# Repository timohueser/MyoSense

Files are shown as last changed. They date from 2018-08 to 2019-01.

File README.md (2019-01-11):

# MyoSense
## Overview
MyoSense is a armband designed to wirelessly track and interpret muscle activity in the forearm to predict handmovements. It uses a custom designed 2.4GHz interface to transmit the signals collected by up to eight sensors to a receiver that can be read out over a standard serial interface. The armband uses dry stainless steel electrodes incorporated into the sensor modules that can pick up the electromygraphic signal generated by muscle activity. Using external adhesive electrodes that can be attached to each sensor MyoSense is also able to read out activity of bigger muscles extendig it's possible usecases to tracking movements of all extremities. 

## Technical Details
### Sensor Modules
<p align="center">
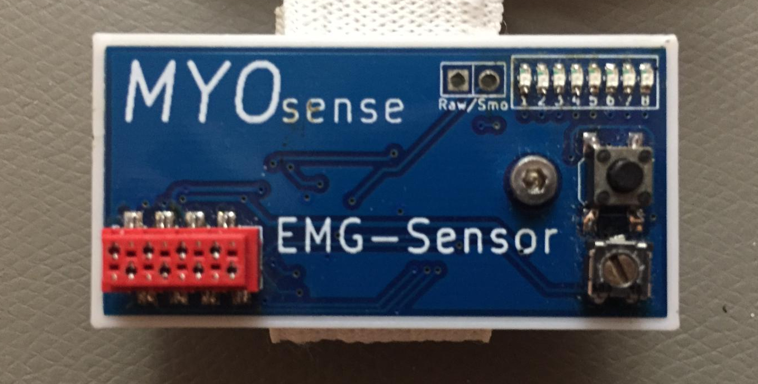
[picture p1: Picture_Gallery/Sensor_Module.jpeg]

</p>

As mentioned before the MyoSense Sensor Modules use dry stainless steel electrodes to pick up the small voltages generated by muscle activity on the skin above the monitored muscle. These voltages get amplified, bandpass-filtered and rectified using analog circuitry. It should be noted that filtering includes a 50Hz mains frequence notch filter, since the body picks this noise up very strongly. After the rectification the signal gets smoothed, or averaged, by a lowpass filter stage. This results in a DC voltage level that is proportional to the strength of muscle activity. Smoothing the signal has the advantage to be able to sample it at very low frequencies, On the other hand Information that could be extracted from the frequency of the EMG śignal, like the level of muscle fatigue is lost. 

<p align="center">
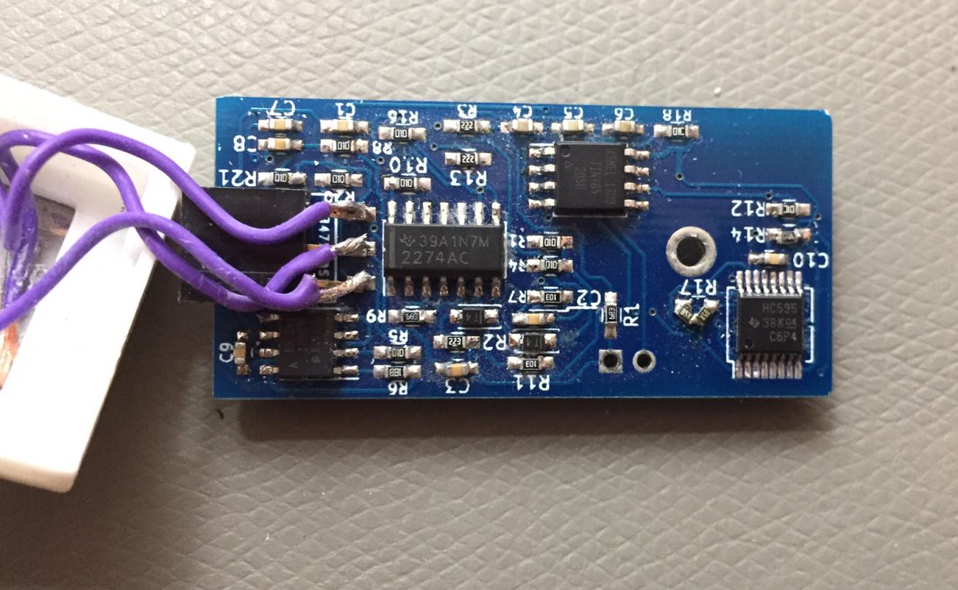
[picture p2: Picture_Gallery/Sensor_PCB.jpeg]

</p>

The processed signal gets digitized by an Attiny85 microcontroller that in turn uses an I2C interface to send the measured voltages to the control module. A push-button on the sensor allows the user to set the I2C adress of the module, allowing up to eight sensors to be used with one control module. The modules consist of a custom design PCB, 3 stainless steel plates serving as the electrodes and a 3D-printed housing. The Kicad design files for the PCB and STL files of the housing can be found in the repository. 

### Control Module
The control module not only is responsible for reading out the senors and transmitting the collected data via a 2.4GHz interfaceto the receiver unit described below, it also contains circuitry to charge a 250 mAh Lipo Battery and supply the requiered 3V and -3V power rails to the sensor modules. In addition it also contains a MCP2221 I2C/UART to USB interface IC enabling direct wired acces to the I2C bus through the same Micro-USB port that is used for charging. 
The wireless communication module used is custom designed and uses the Nordic Semi nRF24L01 2.4GHz transciever IC controlled by an Attiny85 mircrocontroller that also controlls the sensors over the I2C bus. Both the control and the sensor modules can be reprogrammed using the ICSP compatible connector that is also used to connect them with eachother. 

### Wireless receiver and GUI
<p align="center">
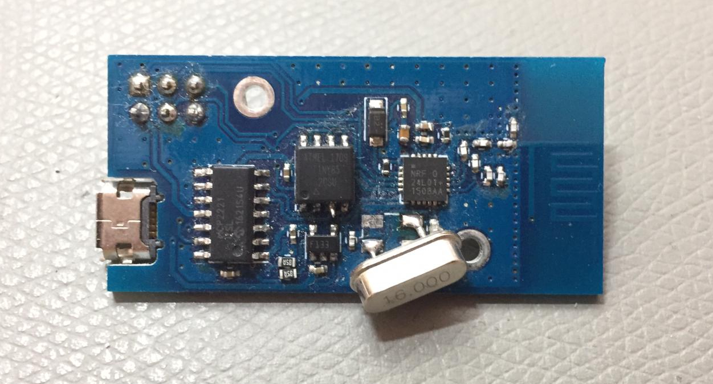
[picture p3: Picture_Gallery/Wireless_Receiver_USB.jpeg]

</p>

The wireless receiver also uses the nRF24L01 transciever and Attiny85 microcontroller as the transmitter module. The microcontroller then connects to another MCP2221 USB interface IC to be able to transmit the received data to a computer over a standard serial interface. The repository also contains an UI-Program implementet in c++ using QT that allows easy access to the receiver module and visualizes the data collected. The repository also contains a python script that implements a neural network that can be used to classify different movement patterns. At the moment this functionality is not available in the GUI, but it is planned to integrate this feature.

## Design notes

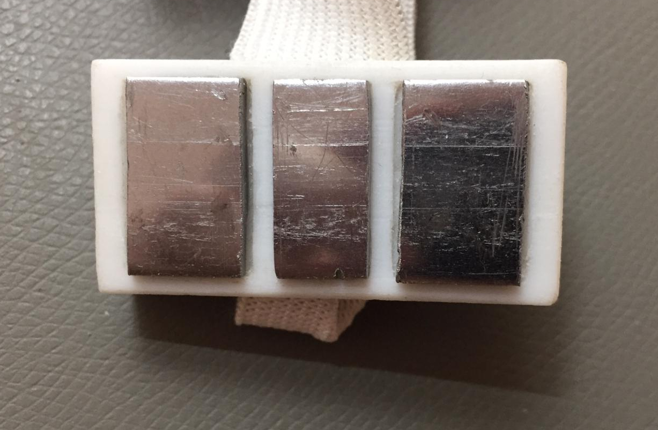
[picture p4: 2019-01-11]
Picture_Gallery/Electrode_Pads.jpeg

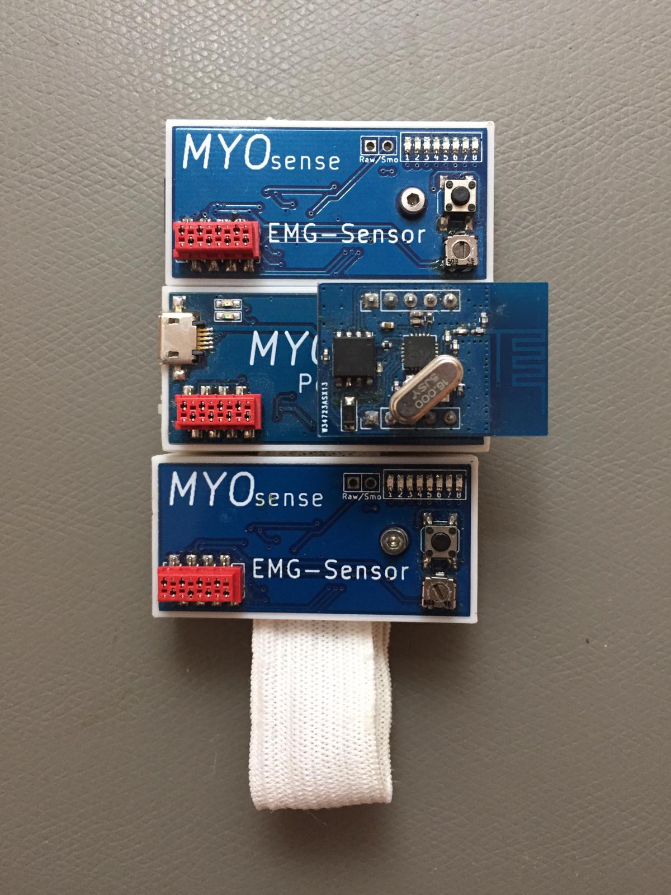
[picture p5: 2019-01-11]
Picture_Gallery/MyoSense_Armband.jpeg

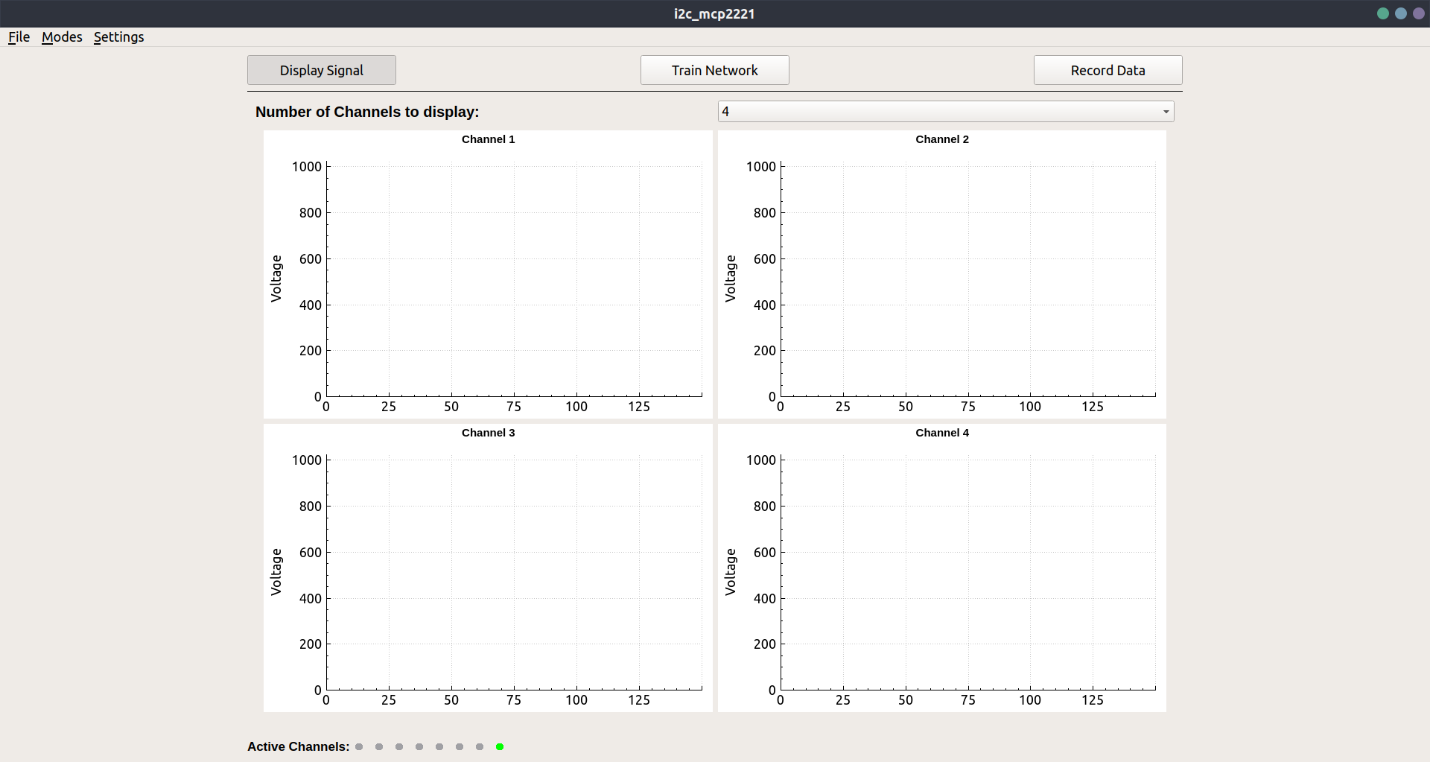
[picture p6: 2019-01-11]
Picture_Gallery/User_Interface.png

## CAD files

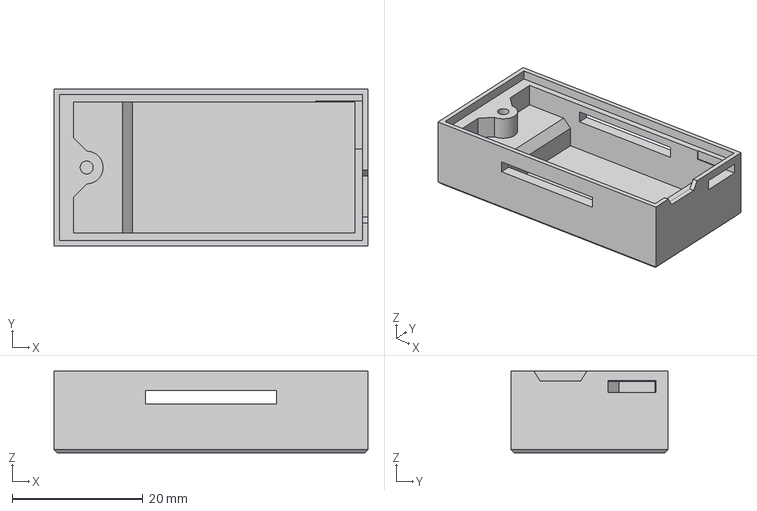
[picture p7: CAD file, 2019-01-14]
3D_Files/Control_Housing/Control_Housing.step
48.0 x 24.0 x 12.5 mm

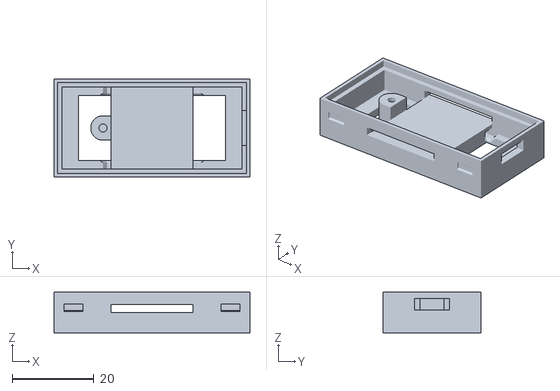
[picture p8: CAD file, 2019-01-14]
3D_Files/Sensor_Housing/Senor_Housing.stl
48.0 x 24.0 x 10.0

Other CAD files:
3D_Files/Sensor_Housing/Sensor_Housing.step
3D_Files/Control_Housing/Control_Housing.stl

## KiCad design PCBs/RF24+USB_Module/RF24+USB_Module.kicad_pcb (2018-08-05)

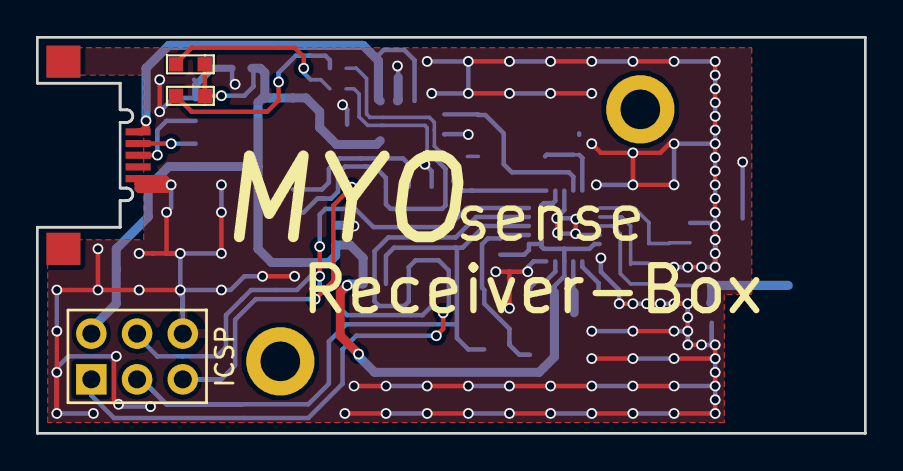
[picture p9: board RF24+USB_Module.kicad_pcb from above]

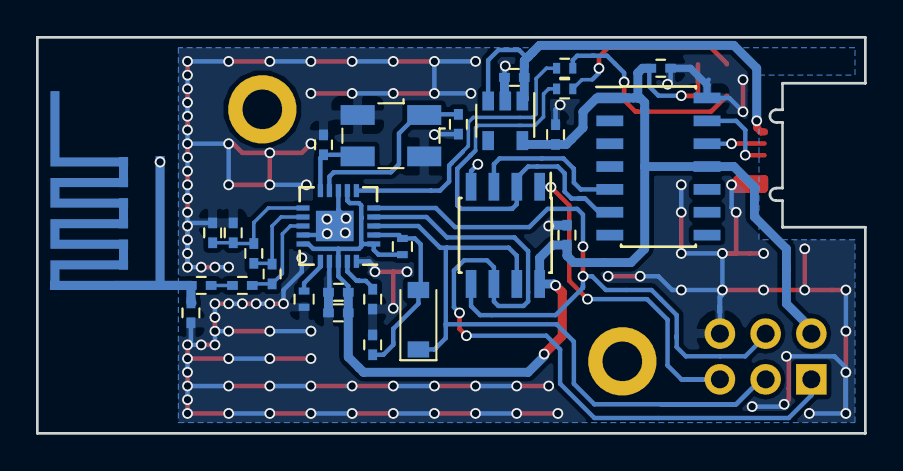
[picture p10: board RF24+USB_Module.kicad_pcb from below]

Board: 2 copper layers, 46.0 x 22.0 mm, 32 parts (29 on the bottom side), 24 nets.

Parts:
AE1: Antenna_Dipole; MIFA-Antenna
C1, C4, C12: 100nF; C_0402
C2: 33nF; C_0402
C3: 1uF; C_0402
C5: 10nF; C_0402
C6: 1.5pF; C_0402
C7: 1.0pF; C_0402
C8: 2.2pF; C_0402
C9: 4.7pF; C_0402
C10, C11: 22pF; C_0402
C13, C14: C_Small; C_0402
D1: 1N4148; D_SOD-123
D2, D3: LED_Small; LED_0603
J1: CONN_01X05; Micro_B_Conrad
J2: ICSP; Socket_Strip_Straight_2x03_Pitch2.54mm
L1: 3.9nH; C_0402
L2: 8.2nH; C_0402
L3: 2.7nH; C_0402
R1: 22k; R_0402
R2: 4.7k; R_0402
R3, R4: R_Small; R_0402
U1: ATTINY85-20SU; SOIC-8_3.9x4.9mm_Pitch1.27mm
U2: nRF24l01+; QFN-20-1EP_4x4mm_Pitch0.5mm
U3: MCP2221; SOIC-14_3.9x8.7mm_Pitch1.27mm
U4: MIC5504; SOT-23-5
Y1: Crystal_GND24; Crystal_SMD_EuroQuartz_MJ-4pin_5.0x3.2mm

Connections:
GND: AE1.2, C1.2, C2.2, C3.2, C4.2, C5.2, C7.2, C8.2, C9.2, C10.2, C11.2, C12.1, C13.2, C14.2, J1.5, J2.6, R1.1, U1.4, U2.8, U2.14, U2.17, U2.20, U3.14, U4.2, Y1.2, Y1.4
IRQ: R3.2, U2.6
MISO: J2.1, U1.6, U2.4
MOSI: J2.4, U1.5, U2.5
unnamed: AE1.1, C6.1, C7.1
unnamed: C2.1, U2.19
unnamed: C5.1, D1.2, R2.2, U2.2
unnamed: C6.2, L1.2
unnamed: C8.1, C9.1, L3.1, U2.11
unnamed: C10.1, U2.9, Y1.1
unnamed: C11.1, U2.10, Y1.3
unnamed: D2.1, R3.1
unnamed: D3.1, R4.1
unnamed: J1.2, U3.12
unnamed: J1.3, U3.13
unnamed: L1.1, L2.1, U2.13
unnamed: L2.2, L3.2, U2.12
unnamed: R1.2, U2.16
RST: J2.5, U1.1
Rx: U1.3, U3.5
SCK: D1.1, J2.3, U1.7, U2.3
Tx: R4.2, U1.2, U3.6
VCC: C1.1, C3.1, C4.1, C12.2, C14.1, D2.2, D3.2, J2.2, R2.1, U1.8, U2.1, U2.7, U2.15, U2.18, U3.1, U3.11, U4.5
V_USB: C13.1, J1.1, U4.1, U4.3

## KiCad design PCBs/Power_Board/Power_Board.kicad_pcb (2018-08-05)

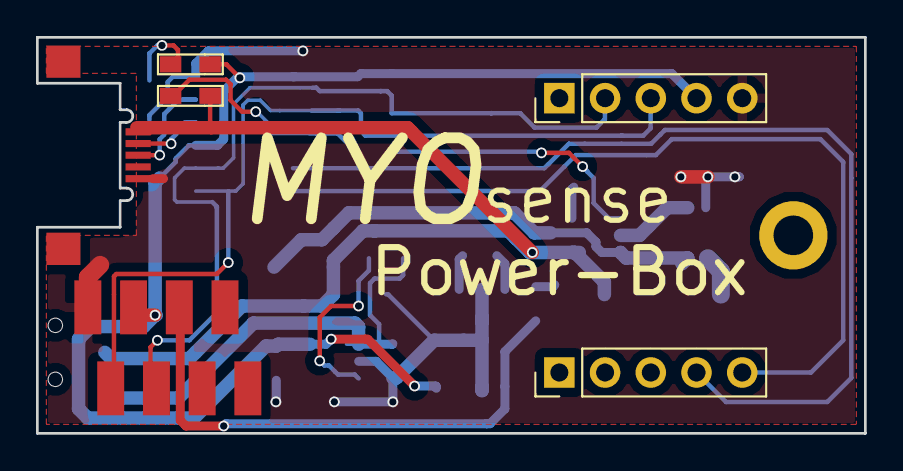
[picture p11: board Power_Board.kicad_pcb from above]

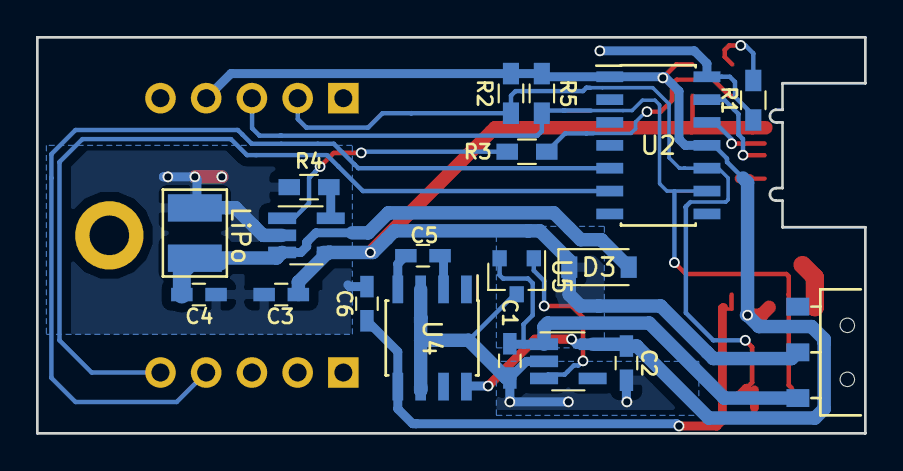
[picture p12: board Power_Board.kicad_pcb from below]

Board: 2 copper layers, 46.0 x 22.0 mm, 25 parts (19 on the bottom side), 19 nets.

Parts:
C1, C2: 1uF; C_0603_HandSoldering
C3, C4: 4.7uF; C_0603_HandSoldering
C5, C6: C; C_0603_HandSoldering
D1, D2: LED; LED_0603_HandSoldering
D3: MBR120; D_SOD-123
J2: LIPO; LiPo_Conn
J3: CONN_02X04; Micro_Match_02x04
J4: CONN_01X05; Micro_B_Conrad
J5, J6: CONN_01X05; Socket_Strip_Straight_1x05_Pitch2.54mm
R1, R2, R3, R4, R5: R; R_0603_HandSoldering
SW1: SW_DPDT_x2; slide_switch_conrad
U1: MIC5504; SOT-23-5_HandSoldering
U2: MCP2221; SOIC-14_3.9x8.7mm_Pitch1.27mm
U3: MCP73832; SOT-23-5_HandSoldering
U4: Lm2660; SOIC-8_3.9x4.9mm_Pitch1.27mm
U5: MCP100T; SOT-23

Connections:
GND: C1.2, C2.2, C3.2, C4.2, C6.2, J2.1, J3.7, J4.5, J5.5, R1.2, R4.2, U1.2, U2.14, U3.2, U4.3, U4.6, U5.3
LIPO_POS: C4.1, D3.2, J2.2, U3.3
unnamed: C1.1, SW1.1, U1.1, U5.2
unnamed: C5.1, U4.2
unnamed: C5.2, U4.4
unnamed: D1.1, R1.1
unnamed: D2.1, R3.1
unnamed: J4.2, U2.12
unnamed: J4.3, U2.13
unnamed: R3.2, U3.1
unnamed: R4.1, U3.5
unnamed: U1.3, U5.1
Rx: J6.4, U2.5
SCL: J3.6, J5.2, R2.2, U2.10
SDA: J3.8, J5.3, R5.2, U2.9
Tx: J6.5, U2.6
USB_Vin: C3.1, D2.2, D3.1, J4.1, SW1.2, U3.4
VCC: C2.1, D1.2, J3.5, J5.4, R2.1, R5.1, U1.5, U2.1, U2.11, U4.8
VSS: C6.1, J3.3, U4.5

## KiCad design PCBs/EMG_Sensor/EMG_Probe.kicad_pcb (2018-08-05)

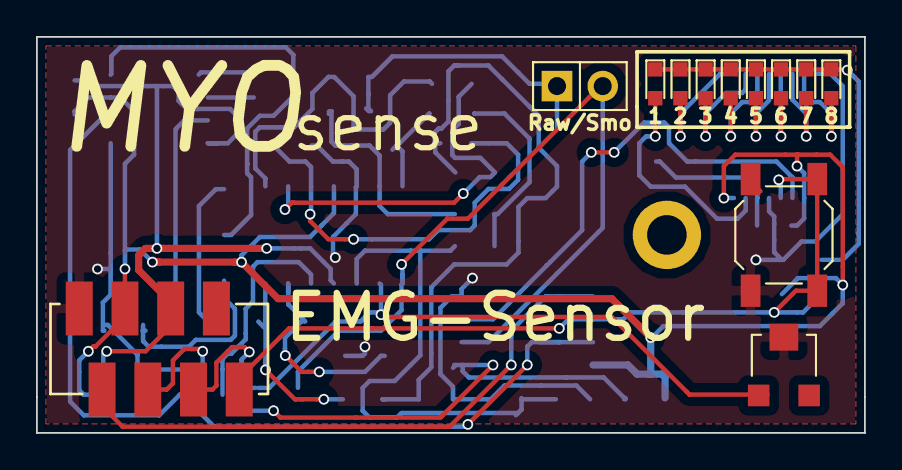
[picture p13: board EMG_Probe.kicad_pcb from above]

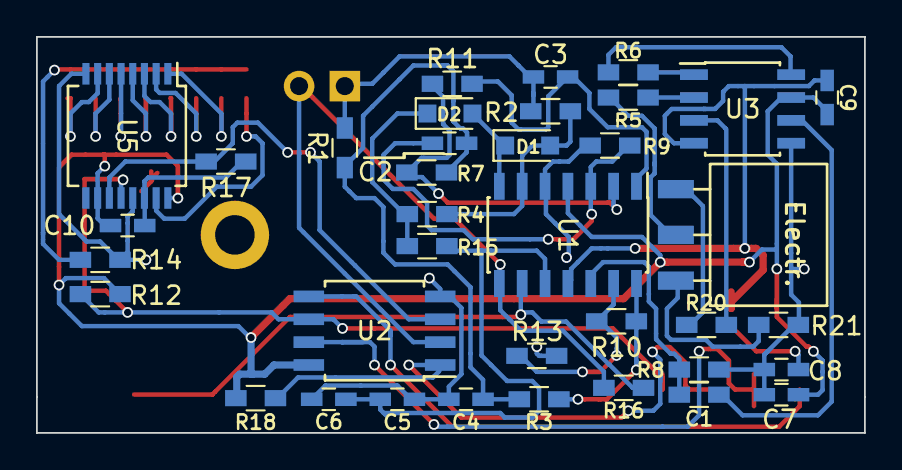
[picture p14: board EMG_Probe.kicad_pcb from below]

Board: 2 copper layers, 46.0 x 22.0 mm, 49 parts (37 on the bottom side), 40 nets.

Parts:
C1: 220n; R_0603_HandSoldering
C2, C3: 47n; C_0603_HandSoldering
C4, C5, C6: 220n; C_0603_HandSoldering
C7, C8, C9, C10: 100n; C_0603_HandSoldering
D1, D2: D; D_SOD-323_HandSoldering
D3, D4, D5, D6, D7, D8, D9, D10: LED; LED_0603
J1: Sensor_Connect; Header_Angled_03
P1: CONN_01X02; Pin_Header_Straight_1x02_Pitch2.54mm
P2: CONN_02X04; Micro_Match_02x04
R1, R9: 68k; R_0603_HandSoldering
R2: 22k; R_0603_HandSoldering
R3, R13: 2k2; R_0603_HandSoldering
R4, R5, R8, R10, R15, R16, R20, R21: 100k; R_0603_HandSoldering
R6: 1.5k; R_0603_HandSoldering
R7, R11, R12, R18: 10k; R_0603_HandSoldering
R14: R; R_0603_HandSoldering
R17: 1k5; R_0603_HandSoldering
RV1: POT; Potentiometer_Trimmer-EVM3E
SW2: SW_PUSH; SW_SPST_SKQG
U1: TLV274; SOIC-14_3.9x8.7mm_Pitch1.27mm
U2: ATTINY85-20SU; SOIJ-8_5.3x5.3mm_Pitch1.27mm
U3: INA126; SOIC-8_3.9x4.9mm_Pitch1.27mm
U5: 74HC595; SSOP-16_5.3x6.2mm_Pitch0.65mm

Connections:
Ard_Output: P1.2, R16.1, U1.8, U2.2
GND: C4.1, C5.2, C6.2, C7.1, C8.1, P2.7, R8.2, R9.2, R13.2, R14.2, R21.2, RV1.2, SW2.1, U1.5, U2.4, U3.5, U5.8, U5.13
unnamed: C1.1, R8.1, U1.12
unnamed: C1.2, U3.6
unnamed: C2.1, C4.2, R1.2, R3.1, R7.2
unnamed: C2.2, R9.1, U1.3
unnamed: C3.2, R11.1, U1.1
unnamed: C5.1, C6.1, R15.1, U1.10
unnamed: C10.2, R17.1, U5.14
unnamed: D1.1, D2.2, U1.7
unnamed: D1.2, R2.1, R4.2, U1.6
unnamed: D3.2, U5.15
unnamed: D4.2, U5.1
unnamed: D5.2, U5.2
unnamed: D6.2, U5.3
unnamed: D7.2, U5.4
unnamed: D8.2, U5.5
unnamed: D9.2, U5.6
unnamed: D3.1, D4.1, D5.1, D6.1, D7.1, D8.1, D9.1, D10.1, R14.1
unnamed: D10.2, U5.7
unnamed: J1.1, R5.2
unnamed: J1.2, R20.2
unnamed: J1.3, R21.1
unnamed: P2.2, R12.1, SW2.2, U2.6, U5.12
unnamed: P2.4, R18.1, U2.1
unnamed: R5.1, U3.2
unnamed: R6.1, U3.8
unnamed: R6.2, U3.1
unnamed: R3.2, R10.1, U1.14
unnamed: R10.2, R13.1, U1.13
unnamed: R7.1, R11.2, U1.2
unnamed: R16.2, RV1.1, U1.9
unnamed: R17.2, U2.3, U5.11
unnamed: R20.1, U3.3
Raw_Output: C3.1, P1.1, R1.1, R2.2
SCL: P2.6, U2.7
SDA: P2.8, U2.5
Signal: D2.1, R4.1, R15.2
VCC: C7.2, C9.2, C10.1, P2.5, R12.2, R18.2, U1.4, U2.8, U3.7, U5.10, U5.16
VSS: C8.2, C9.1, P2.3, U1.11, U3.4

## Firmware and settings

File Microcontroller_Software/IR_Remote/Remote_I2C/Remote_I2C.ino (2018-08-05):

#define   F_CPU   16000000UL

#include <avr/io.h>
#include <TinyWireS.h>
#include <util/delay.h>
#include <EEPROM.h>

#ifndef TWI_RX_BUFFER_SIZE
#define TWI_RX_BUFFER_SIZE ( 16 )
#endif
#define DEVICEADDRESS 0b1010000
#define P_LEN 130
#define P_AM 10


#define BUTTON_1 0
#define BUTTON_2 2
#define CARRIER 1
#define TRAN_TOGGLE 3
#define SENSOR 4

unsigned int pulse_len[P_AM];
byte pulses[P_LEN];
unsigned long microseconds = 0;
byte h  = 0;
byte mode = 0;
byte cmd = 0;


void setup() {
  TCCR0A = 1 << COM0B0 | 2 << WGM00;
  TCCR0B = 1 << WGM02 | 1 << CS00;
  OCR0A = (16000000ul / 40000u / 2u) - 1u; //overflow twice per 40kHz period
  TIMSK |= (1 << OCIE0A);
  sei();
  memset(pulse_len, 0, sizeof(pulse_len));
  memset(pulses, 0, sizeof(pulses));
  pinMode(SENSOR, INPUT);
  pinMode(CARRIER, OUTPUT);
  pinMode(TRAN_TOGGLE, OUTPUT);
  TinyWireS.begin(1);
  TinyWireS.onReceive(receiveEvent);
}


void receiveEvent(uint8_t howMany) {
  mode = TinyWireS.receive();
  cmd = TinyWireS.receive();
  if (cmd > 5) cmd = 0;
}


void scan_signal() {
  memset(pulse_len, 0, sizeof(pulse_len));
  memset(pulses, 0, sizeof(pulses));
  unsigned long start_pulse;
  unsigned int count = 0;
  unsigned long start_scan = microseconds;
  while (digitalRead(SENSOR) && microseconds - start_scan < 10000000) _delay_us(1);
  while (count < P_LEN) {
    start_pulse = microseconds;
    int timeout = edge_detect();
    if (timeout == 0) return;
    add_pulse(count++, microseconds - start_pulse);
  }
}

int edge_detect() {
  int prev_val = digitalRead(SENSOR);
  int new_val;
  unsigned long start = microseconds;
  while (prev_val - (new_val = digitalRead(SENSOR)) == 0) {
    if (microseconds - start > 100000) return 0;
    prev_val = new_val;
    _delay_us(1);
  }
  return 1;
}

void add_pulse(int counter, int dur) {
  byte pulse_num = 0;
  for (int i = 0; i  < P_AM; i++) {
    if (((dur - 100) <= pulse_len[i] && (dur + 100) >= pulse_len[i]) || pulse_len[i] == 0)  {
      pulse_num = i + 1;
      if (pulse_len[i] == 0) pulse_len[i] = dur;
      i = P_AM;
    }
  }
  pulses[counter] = pulse_num;
}



ISR (TIMER0_COMPA_vect)
{
  if (h == 0) microseconds += 25;
  h = (h + 1) % 2;
}


void store_signal(int slot) {
  for (int i = 0; i < P_AM; i++) {
    EEPROM.write(2 * i + slot * (P_LEN / 2 + P_AM * 2), pulse_len[i] >> 8);
    EEPROM.write(2 * i + 1 + slot * (P_LEN / 2 + P_AM * 2), pulse_len[i]);
  }
  for (int i = 0; i  < P_LEN / 2; i++) {
    byte str_val = pulses[2 * i];
    str_val += pulses[2 * i + 1] << 4;
    EEPROM.write(i + P_AM * 2 + slot * (P_LEN / 2 + P_AM * 2), str_val);
  }
}

void load_signal(int slot) {
  for (int i = 0; i < P_AM; i++) {
    pulse_len[i] = EEPROM.read(2 * i + slot * (P_LEN / 2 + P_AM * 2)) * 256;
    pulse_len[i] += EEPROM.read(2 * i + 1 + slot * (P_LEN / 2 + P_AM * 2));
  }
  for (int i = 0; i < P_LEN / 2; i++) {
    int rd_val = EEPROM.read(i + P_AM * 2 + slot * (P_LEN / 2 + P_AM * 2));
    pulses[2 * i] = (rd_val & B00001111);
    pulses[2 * i + 1] = (rd_val & B11110000) >> 4;
  }

}

void send_signal() {
  digitalWrite(TRAN_TOGGLE, HIGH);
  byte state = 0;
  for (int i = 0; i < P_LEN; i++) {
    if (pulses[i]) {
      digitalWrite(TRAN_TOGGLE, state = (state + 1) % 2);
      unsigned long start = microseconds;
      while (microseconds - start < pulse_len[pulses[i] - 1]) _delay_us(1);
    }
    else {
      digitalWrite(TRAN_TOGGLE, LOW);
      return;
    }
  }
  digitalWrite(TRAN_TOGGLE, LOW);
}






void loop() {
  TinyWireS_stop_check();
  if (mode == 1) {
    scan_signal();
    store_signal(cmd);
    mode = 0;
    cmd = 0;
  }
  else if (mode == 2) {
    load_signal(cmd);
    send_signal();
    mode = 0;
    cmd = 0;
  }
  else if (mode == 3) {
    mode = 0;
    cmd = 0;
  }

}

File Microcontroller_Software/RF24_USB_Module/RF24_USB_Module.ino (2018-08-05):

#include "SoftwareSerial_tiny.h"
#include "RF24.h"

RF24 radio(3, 3);
SoftwareSerial_tiny TinySerial(3, 4); // RX, TX

byte addresses[][6] = {"1Node", "2Node"};
byte instruction[2] = {0, 0};
byte handshake[2] = {0, 1};
uint16_t single_voltage;
byte active_sensors[8] = {1, 1, 0, 0, 0, 0, 0, 0};
int16_t voltages[8];
int num_active_channels = 2;
int16_t voltages_alt[8] = {0, 0, 0, 0, 0, 0, 0, 0};


void setup() {
  radio.begin();
  radio.setPALevel(RF24_PA_HIGH);
  radio.setDataRate( RF24_2MBPS );
  radio.enableDynamicPayloads();                // Ack payloads are dynamic payloads
  radio.openWritingPipe(addresses[0]);
  radio.openReadingPipe(1, addresses[1]);
  radio.setRetries(1, 1);
  radio.stopListening();
  TinySerial.begin(19200);


}

void loop() {
  if (TinySerial.available()) {
    unsigned long start = millis();
    while (TinySerial.available() < 2);
    if (TinySerial.available() == 2) {
      TinySerial.read(instruction, 2);
      TinySerial.flush();
      radio.write(instruction, 2);
      radio.startListening();
      if (instruction[0] == 0) {
        if (instruction[1] == 0) {
          radio.flush_rx();
          delay(10);
          if (radio.available()) {
            radio.read(active_sensors, 8);
            TinySerial.write(active_sensors, sizeof(active_sensors));
            num_active_channels = 0;
            for (int i = 0; i < 8; i++) {
              num_active_channels += active_sensors[i];
            }
          }
          else {
            TinySerial.write(active_sensors, sizeof(active_sensors));
          }
        }
        else if (instruction[1] == 1) {
          byte conn = 0;
          unsigned long start = millis();
          while (millis() - start < 2000 && !radio.available()) {
            radio.stopListening();
            radio.write(handshake, sizeof(handshake));
            radio.startListening();
            unsigned long start2 = millis();
            while (!radio.available() && millis() - start2 < 50);
          }
          if (radio.available()) conn = 1;
          radio.flush_rx();
          TinySerial.write(&conn, 1);
        }
      }
      else if (instruction[0] == 1) {
        if (instruction[1] == 0) {
          unsigned long start = millis();
          while (!radio.available() && millis() - start < 10);
          if (radio.available()) {
            radio.read(voltages, num_active_channels * 2);
            TinySerial.write(voltages, num_active_channels * 2);
          }
          else {
            voltages[0] = 127;
            TinySerial.write(voltages, num_active_channels * 2);
          }
        }
        else if (instruction[1] == 1) {
          while (!radio.available() && !TinySerial.available());
          if (!TinySerial.available()) {
            for (int i = 0; i < 75; i++) {
              unsigned long start = millis();
              while (!radio.available() && millis() - start < 10);
              if (radio.available()) {
                radio.read(voltages, num_active_channels * 2);
                TinySerial.write(voltages, num_active_channels * 2);
              }
              else TinySerial.write(voltages_alt, num_active_channels * 2);
            }
          }
        }
      }
    }
    else TinySerial.flush();
    radio.stopListening();

  }
}
